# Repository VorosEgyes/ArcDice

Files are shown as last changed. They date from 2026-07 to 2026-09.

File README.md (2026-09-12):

# ArcDice



ArcDice is a compact ATtiny13-based digital dice project with a 7-LED face, low-power sleep behavior, and a matching KiCad hardware design.

Keywords: digital dice, ATtiny13 dice, LED dice, DIY electronic dice.

## What It Does

- Rolls a random value from 1 to 6 with a short LED animation.
- Drives a 7-point dice face from only 4 MCU output lines.
- Uses button wake-up and sleep mode to reduce power draw.

## Firmware

- Source: `src/main.cpp`
- PlatformIO environment: `attiny13a`
- Upload protocol: `usbasp`

### Pin Mapping

- PB0 -> center LED segment
- PB1 -> diagonal A (top-left + bottom-right)
- PB2 -> diagonal B (top-right + bottom-left)
- PB3 -> middle row (left-middle + right-middle)
- PB4 -> roll button (to GND, internal pull-up)

### Dice Face Layout

The 7 visible pips are arranged on a 3x3 grid and lit via 4 logical
groups (center, two diagonals, middle row). The resulting faces are:

| Roll | Pattern | Description |
|---|---|---|
| 1 | center | single center pip |
| 2 | diagonal A | two corner pips (TL+BR) |
| 3 | center + diagonal A | vertical middle column (TL + center + BR) |
| 4 | diagonal A + diagonal B | four corners (full X) |
| 5 | center + both diagonals | full X plus center |
| 6 | both diagonals + middle row | four corners + middle two |

Note: face 3 uses diagonal A (TL+BR) plus center, giving a symmetric
vertical middle column -- the standard 7-pip rendering of 3.

## Hardware

- KiCad project files:
	- `hardware/ArcDice.kicad_pro`
	- `hardware/ArcDice.kicad_sch`
	- `hardware/ArcDice.kicad_pcb`
- Power target: 1S Li-ion/LiPo with TP4056 protected module
- Recommended LED resistors: 220 ohm (one per LED)

## Images

### Assembled Board

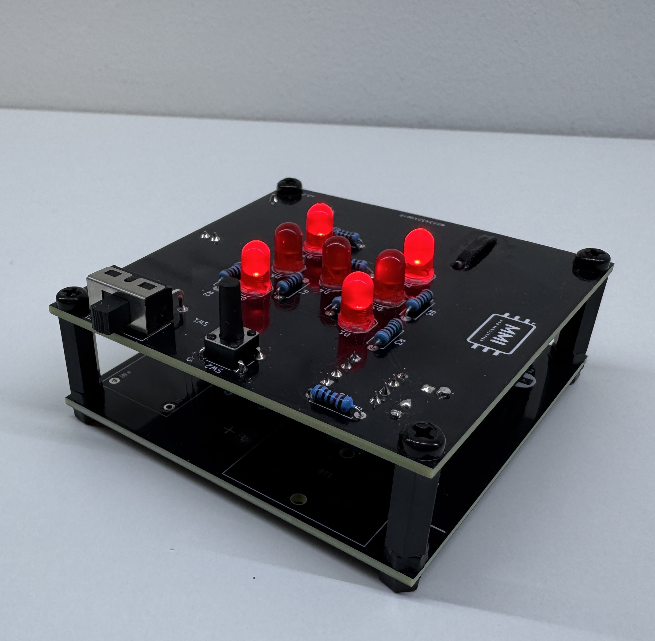
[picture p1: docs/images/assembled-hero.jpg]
ArcDice assembled, all segments lit


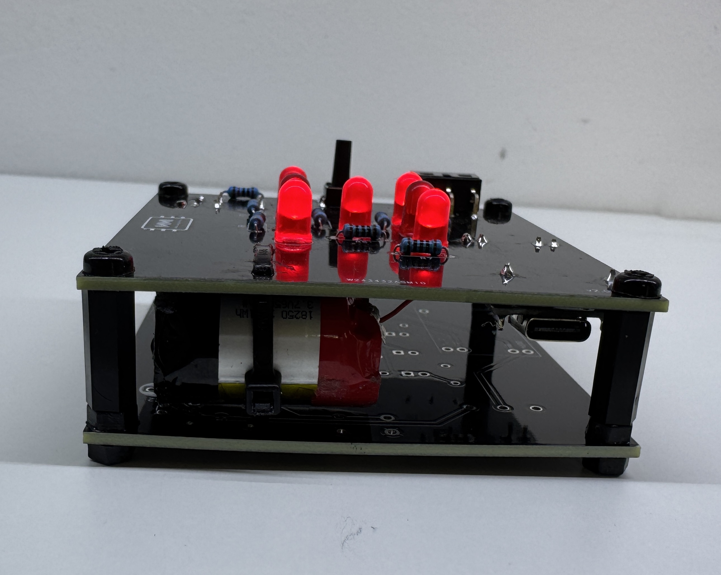
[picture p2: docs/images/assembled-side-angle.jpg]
ArcDice assembled, side angle showing battery


### Bare PCB

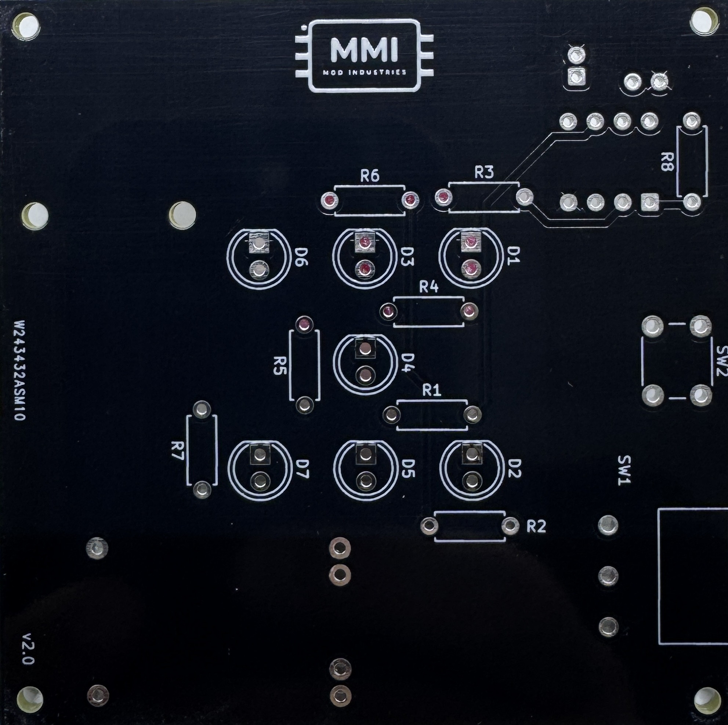
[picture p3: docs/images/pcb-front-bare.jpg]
ArcDice bare PCB, front


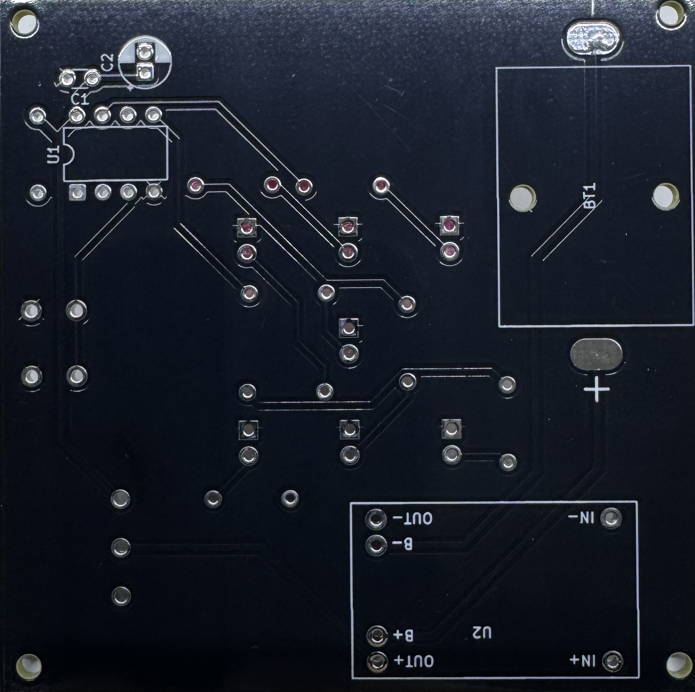
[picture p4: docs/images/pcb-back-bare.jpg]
ArcDice bare PCB, back


### 3D Top

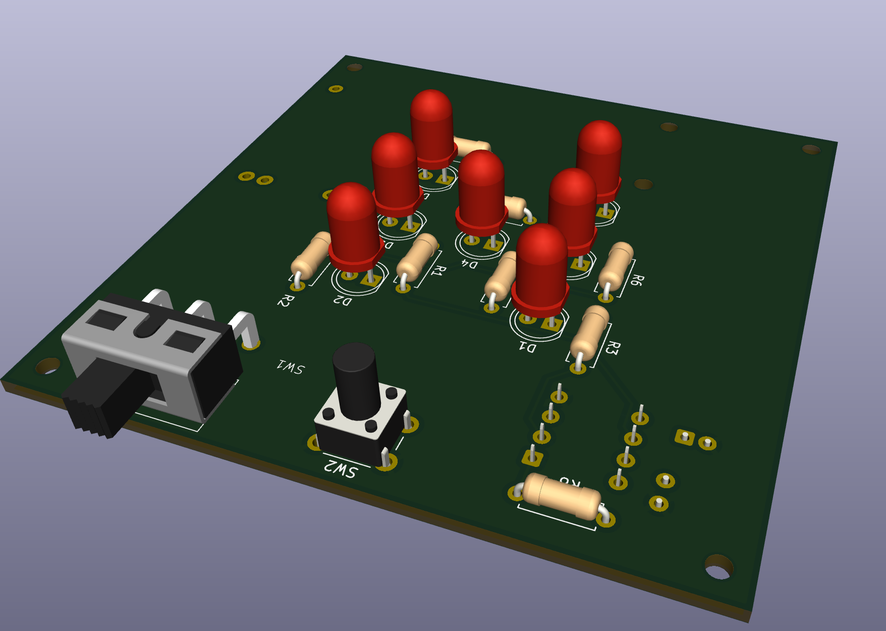
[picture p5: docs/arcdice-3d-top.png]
ArcDice 3D top


### 3D Bottom

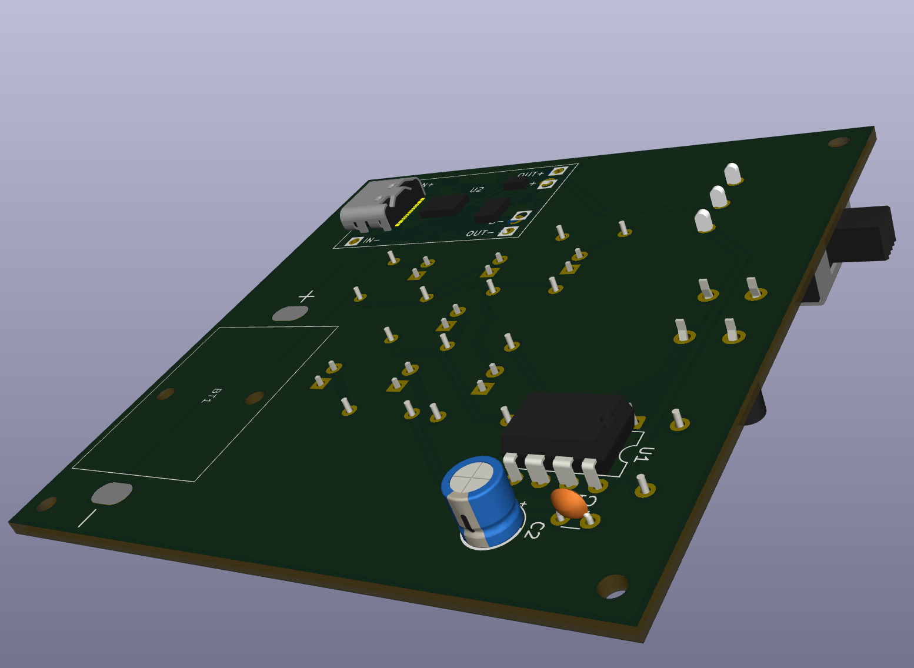
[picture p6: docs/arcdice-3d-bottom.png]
ArcDice 3D bottom


### Schematic v1

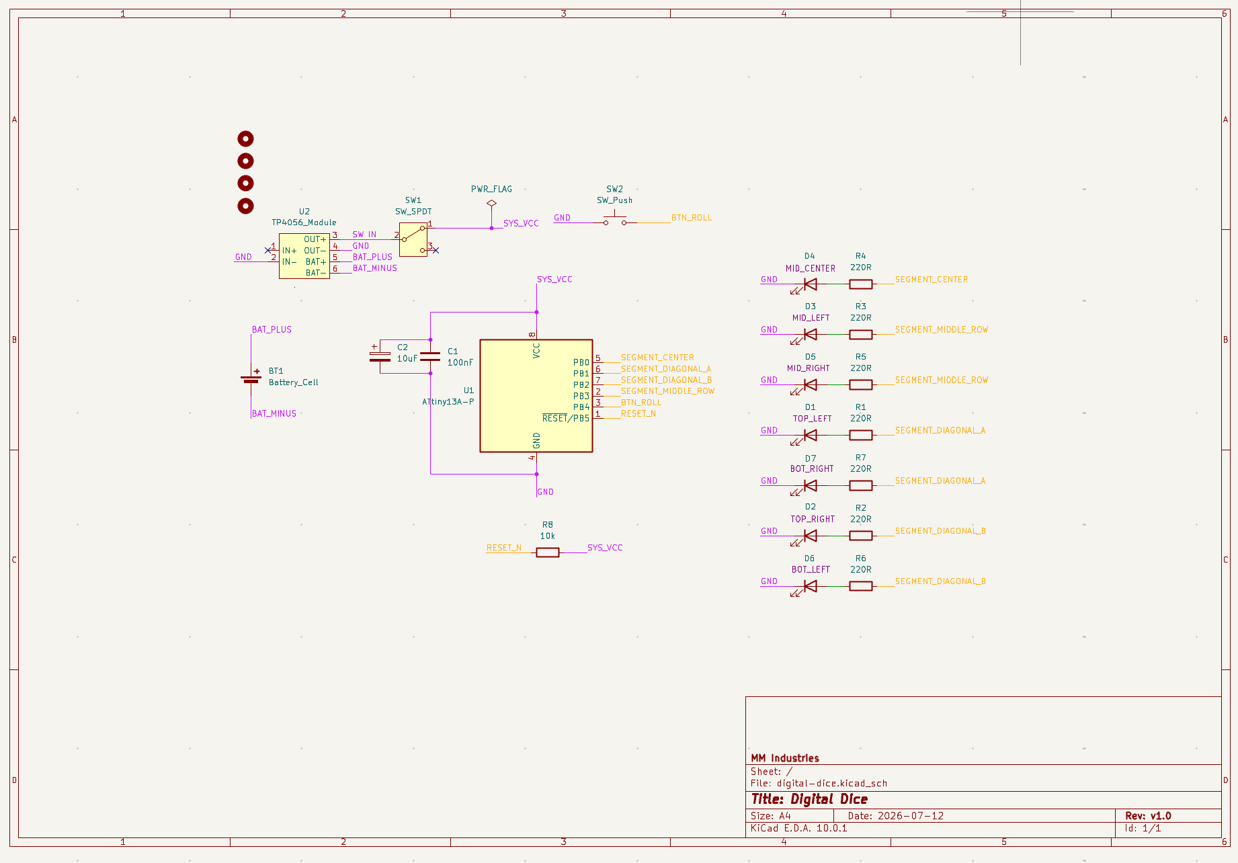
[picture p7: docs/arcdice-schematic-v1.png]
ArcDice schematic v1


## Build And Upload

1. Install PlatformIO.
2. Connect an ATtiny13 programmer (USBasp).
3. Build and upload:

```bash
pio run -e attiny13a -t upload
```

## Additional Documentation

- [CHANGELOG.md](CHANGELOG.md) — release history and notable changes.
- [docs/BOM.md](docs/BOM.md) — bill of materials with footprints and suggested supplier parts.

## License

MIT. See `LICENSE`.

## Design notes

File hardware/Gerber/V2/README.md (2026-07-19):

# Gerber V2 — ArcDice PCB revision 2

This folder contains the PCBWay-ready Gerber archive for ArcDice revision 2.

## Files

| File | Purpose |
|---|---|
| `Archive.zip` | Complete submission package (all files below + job metadata). Send this to PCBWay. |
| `ArcDice-F_Cu.gbr` | Front copper (top layer, signal + 5V + GND pours) |
| `ArcDice-B_Cu.gbr` | Back copper (bottom layer, GND pour) |
| `ArcDice-F_Mask.gbr` | Front soldermask |
| `ArcDice-B_Mask.gbr` | Back soldermask |
| `ArcDice-F_Paste.gbr` | Front solder paste (SMD footprints; this board is through-hole so this layer is mostly empty) |
| `ArcDice-B_Paste.gbr` | Back solder paste |
| `ArcDice-F_Silkscreen.gbr` | Front silkscreen (reference designators, logo, "ArcDice V2") |
| `ArcDice-B_Silkscreen.gbr` | Back silkscreen |
| `ArcDice-Edge_Cuts.gbr` | Board outline |
| `ArcDice-PTH-drl.gbr` | Plated through-hole drill file |
| `ArcDice-NPTH-drl.gbr` | Non-plated through-hole drill file (M2 mounting holes) |
| `ArcDice-job.gbrjob` | KiCad job file describing the export — used by PCBWay to verify the package |

## Specifications

| | |
|---|---|
| **Board dimensions** | (See `ArcDice-Edge_Cuts.gbr` — open in KiCad or any Gerber viewer) |
| **Layers** | 2 (front + back) |
| **Material** | FR4 |
| **Thickness** | 1.6 mm (default; change in PCBWay order form if needed) |
| **Copper weight** | 1 oz/ft² (default) |
| **Surface finish** | HASL lead-free recommended for through-hole; ENIG also fine |
| **Soldermask colour** | Any (green is cheapest; black shows silkscreen best) |
| **Silkscreen colour** | White |
| **Min hole size** | 0.8 mm (drill diameter — through-hole pads) |
| **Min trace / space** | 0.2 mm / 0.2 mm (KiCad default; PCBWay standard) |

## Changes from V1 (if applicable)

*V1 is not in the repository — only V2 shipped publicly.*

If you ordered from a previous (pre-V2) prototype, the main changes were:

- (none — V2 is the first publicly archived revision)

## How to order

1. Go to https://www.pcbway.com/ (or any PCB house: JLCPCB, ALLPCB, etc.).
2. Click **Quick Order** → **Gerber Upload**.
3. Upload `Archive.zip`.
4. PCBWay will parse `ArcDice-job.gbrjob` and pre-fill layer count,
   material, and dimensions. Confirm:
   - **Layers**: 2
   - **Material**: FR4
   - **Thickness**: 1.6 mm
   - **Quantity**: whatever you need (5 / 10 / 30 / 50).
5. Add to cart. Choose shipping. Done.

For assembly, see [`../docs/BOM.md`](../docs/BOM.md) for the through-hole
parts. This board has no SMD components, so hand-soldering or wave
soldering both work; reflow is not required.

## Reproducing the Gerber export

If you change the schematic or PCB and want to regenerate this folder:

1. Open `../ArcDice.kicad_pro` in KiCad 8 or later.
2. **Plot** → choose **Gerber** as the format.
3. Select **all layers** you want (F.Cu, B.Cu, F.Mask, B.Mask,
   F.Paste, B.Paste, F.SilkS, B.SilkS, Edge.Cuts).
4. Check **Use Protel filename extensions** is enabled (so the
   `.gbr` filenames match).
5. Click **Plot**.
6. **Generate Drill Files** → PTH and NPTH in separate files.
   Use **Gerber X2** format.
7. Archive the generated `.gbr` + `.drl` + `*-job.gbrjob` into
   `Archive.zip`.
8. Move the previous folder to `Gerber/V3/`, update this README with
   the change log, and tag the commit as `hw-v3`.

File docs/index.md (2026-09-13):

---
layout: default
title: ATtiny13 Digital Dice
---

<div class="hero">
  <div class="hero-text">
    <h1>ArcDice</h1>
    <p class="tagline">An open-source digital dice built from an ATtiny13A — 1 KB of flash, 7 LEDs, one button, infinite rolls.</p>
    <div class="cta-row">
      <a class="cta-button" href="{{ '/#download' | relative_url }}">Download v1.1.0</a>
      <a class="cta-button secondary" href="{{ site.github_url }}">View on GitHub ↗</a>
      <a class="cta-button secondary" href="{{ '/#demo' | relative_url }}">Watch demo</a>
    </div>
  </div>
  <div class="hero-image">
    ArcDice assembled prototype with all 7 LEDs lit showing a 6
  </div>
</div>

## What is it?

ArcDice is a complete DIY electronics project: a pocket-sized digital dice you build yourself. Press the button, watch the 7-LED display animate, and a random number from 1 to 6 appears.

It's built around an **ATtiny13A** — one of the smallest AVR microcontrollers Atmel makes, with just **1 KB of flash** and **64 bytes of RAM**. Driving 7 LEDs from only 4 I/O pins uses a clever charlieplexing scheme; the firmware fits in 598 bytes (58.4% of available flash).

The hardware is open (KiCad schematics + PCB layout, MIT licensed), the firmware is open (C++, 39 source files, host-native unit tests), and the BOM has 10 component lines / 26 parts — most of which you probably already have in your parts bin.

## Hardware

- **MCU**: ATtiny13A in DIP-8 (8-bit AVR, 1 KB flash, 64 B RAM, internal 9.6 MHz oscillator)
- **Display**: 7 red LEDs arranged in the classic dice-6 pattern, charlieplexed on PB0–PB3
- **Input**: Single tactile button (wake from sleep on press)
- **Power**: TP4056 Li-ion/LiPo charger module (USB-C or micro-USB variant) with built-in DW01 + FS8205 protection IC
- **Cell**: 1S Li-ion/LiPo (protected, user-supplied, ~600 mAh gives weeks of standby)

### PCB

<div class="gallery-grid">
  <div class="gallery-item">
    PCB front side, unpopulated
    <p class="gallery-caption">PCB front side (bare)</p>
  </div>
  <div class="gallery-item">
    PCB back side, unpopulated
    <p class="gallery-caption">PCB back side (bare)</p>
  </div>
</div>

### Specifications

<table class="spec-table">
  <tr><th>Hardware revision</th><td>v2.1 (KiCad)</td></tr>
  <tr><th>PCB size</th><td>~30 × 30 mm</td></tr>
  <tr><th>Layers</th><td>2 (top + bottom)</td></tr>
  <tr><th>BOM</th><td>10 component lines, 26 parts total</td></tr>
  <tr><th>Power consumption (idle)</th><td>< 10 µA (sleep mode)</td></tr>
  <tr><th>Power consumption (roll)</th><td>~15 mA peak (all 7 LEDs)</td></tr>
  <tr><th>Build time</th><td>~30 minutes (THT parts only)</td></tr>
  <tr><th>License</th><td>MIT</td></tr>
</table>

## Demo

<div class="demo-gif">
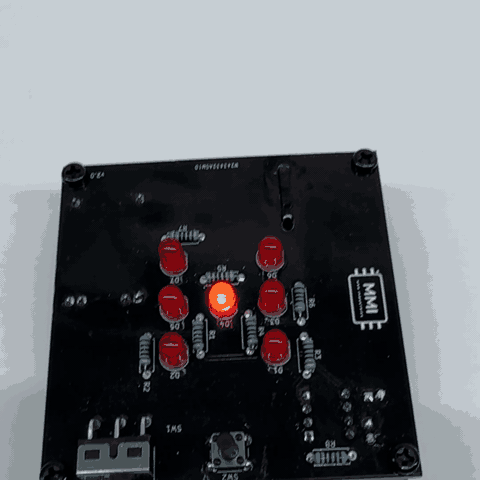
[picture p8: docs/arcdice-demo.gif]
ArcDice demo: button press animates LEDs to a 3
  
  <p><em>Press the button — the 7 LEDs animate for ~1.5 seconds, then settle on a random number from 1 to 6.</em></p>
</div>

The dice face logic is unit-tested against the canonical patterns in `include/dice.h`, with a host-native test runner that runs on any laptop in under a second (`pio test -e native`).

## Gallery

<div class="gallery-grid">
  <div class="gallery-item">
    Assembled ArcDice showing a 6
    <p class="gallery-caption">All 7 LEDs lit — a 6</p>
  </div>
  <div class="gallery-item">
    Side angle showing PCB thickness
    <p class="gallery-caption">Side view — battery + TP4056 visible</p>
  </div>
  <div class="gallery-item">
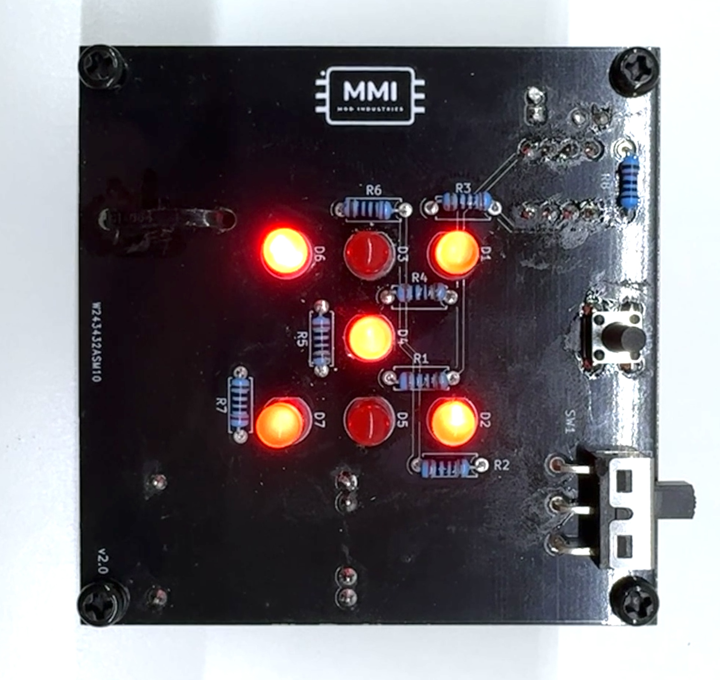
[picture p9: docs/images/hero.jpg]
Hero shot, top-down
    
    <p class="gallery-caption">Top-down view</p>
  </div>
</div>

## Build it yourself

The project ships with everything you need:

- **Pre-compiled firmware** (`ArcDice_v1.1.0_firmware.hex`) — flash with a $5 USBasp and `avrdude` in 30 seconds
- **Gerber package** (`ArcDice_v2.1_gerber.zip`) — upload the inner `Archive.zip` to PCBWay or JLCPCB; ~$5 for 5 boards
- **BOM CSV** (`ArcDice_v2.1_bom.csv`) — 10 lines with KiCad footprints and suggested supplier parts (Digi-Key / LCSC / Mouser)
- **Assembly guide** — step-by-step build instructions with a troubleshooting table

Total cost of parts: roughly **$8–12** if you're sourcing everything new, less if you have a parts bin.

```bash
# Flash the firmware
avrdude -c usbasp -p attiny13 -U flash:w:ArcDice_v1.1.0_firmware.hex:i
```

The full build takes about 30 minutes if you've soldered through-hole before.

## Download

Latest release: **[v1.1.0 — Hardware v2.1]({{ site.github_url }}/releases/tag/v1.1.0)** (2026-09-11)

| Asset | Size | Description |
|---|---:|---|
| [ArcDice_v1.1.0_firmware.hex]({{ site.github_url }}/releases/download/v1.1.0/ArcDice_v1.1.0_firmware.hex) | 1.7 KB | Pre-compiled ATtiny13A firmware |
| [ArcDice_v2.1_gerber.zip]({{ site.github_url }}/releases/download/v1.1.0/ArcDice_v2.1_gerber.zip) | 208 KB | PCBWay-ready Gerber package |
| [ArcDice_v2.1_bom.csv]({{ site.github_url }}/releases/download/v1.1.0/ArcDice_v2.1_bom.csv) | 2.7 KB | Bill of Materials (10 lines, 26 parts) |
| [ArcDice_v2.1_assembly_guide.md]({{ site.github_url }}/releases/download/v1.1.0/ArcDice_v2.1_assembly_guide.md) | 4.8 KB | 6-step build instructions |

**SHA256** (firmware):
```
3bb64ebeb0fcdb910fa978c3b29c1daba74df96bf88c5c467d6e60e317c714ee
```

Always verify before flashing.

## License

MIT — see [LICENSE]({{ site.github_url }}/blob/main/LICENSE). Schematics, PCB layout, and firmware are all released under the same terms. Feel free to fork, modify, and build your own version.

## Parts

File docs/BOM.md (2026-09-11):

# Bill of Materials (BOM)

This document lists every component needed to build one ArcDice unit.
It is derived from the KiCad project (`hardware/ArcDice.kicad_pro`,
`.kicad_sch`, `.kicad_pcb`) and the firmware pin mapping in
`src/main.cpp`. Footprints are taken straight from the KiCad library
references.

> **Sourcing note** — KiCad footprints identify the *physical package*
> (e.g. `LED_D5.0mm`, `R_Axial_DIN0207`). For exact distributor part numbers
> (Digi-Key, Mouser, LCSC), see the *Suggested supplier parts* column. Any
> equivalent part that matches footprint and electrical specs will work.

## Components

| Ref | Qty | Part (KiCad) | Description | Footprint / package | Suggested supplier part |
|----:|----:|---|---|---|---|
| U1 | 1 | `ATtiny13A-P` | 8-bit AVR MCU, 1 KB flash, 64 B EEPROM, 64 B SRAM, internal 9.6 MHz oscillator | DIP-8 (through-hole) | Microchip ATtiny13A-PU (Digi-Key ATATTINY13A-PU-ND) |
| D1–D7 | 7 | `LED` (generic) | 5 mm through-hole LED — pick your colour (red, yellow, green, blue, white all fit). Forward voltage ~2.0 V (red) to ~3.2 V (blue/white) at 20 mA | `LED_THT:LED_D5.0mm` | Kingbright L-7113ID (red, THT, 5 mm) or any 5 mm LED of your choice |
| R1–R7 | 7 | Resistor 220 Ω, ¼ W | LED current-limiting. With 3.0 V Li-ion and a red LED (~2 V Vf), 220 Ω gives ~5 mA per LED — plenty for a battery-powered dice | `Resistor_THT:R_Axial_DIN0207_L6.3mm_D2.5mm_P7.62mm_Horizontal` | Yageo MFR-25FBF52-220R (Digi-Key 220XBK-ND) |
| SW1 | 1 | `SW_Push` — roll button | 6 mm × 9.5 mm through-hole tactile push button, SPST-NO. Connected to PB4 to GND, internal pull-up enabled in firmware | `Button_Switch_THT:SW_PUSH_6mm_H9.5mm` | C&K PTS810SJM250SMTRLFS or any equivalent 6 mm THT tactile |
| SW2 | 1 | `Switch_Slide_SS12D06_Generic` | SPDT slide switch — most likely the power on/off switch between battery and TP4056 / load | `Button_Switch_THT:Switch_Slide_SS12D06_Generic` | SS12D06G3 or any equivalent SPDT slide switch, THT |
| SW3 | 1 | `SW_SPDT` | Second SPDT switch — check schematic for exact use (likely mode-select or reset disable) | (KiCad symbol `Switch:SW_SPDT`, footprint TBD) | Any SPDT THT slide/toggle switch |
| BT1 | 1 | `Battery_Cell` | Single 3.7 V Li-ion / LiPo cell (1S), nominal capacity 100–500 mAh typical for a dice. Use a protected cell (with BMS) and add a 1N4148 flyback diode if driving the LEDs without other regulation | Through-hole battery holder footprint (KiCad `Device:Battery_Cell`) | 1S Li-ion/LiPo |
| U2 | 1 | `TP4056_Module` | TP4056 Li-ion/LiPo linear charging module, micro-USB or USB-C input depending on the module variant. Charges the cell from any 5 V source; module typically includes a DW01 + FS8205 protection IC. Note: the **module** is mounted, not the bare TP4056 IC | Through-hole 4-pin module (OUT+/OUT−/IN+/IN−) | TP4056 micro-USB module (LCSC C103626) or USB-C variant (LCSC C2932096) |
| C1, C2 | 2 | Decoupling capacitors | Polarized + unpolarized decoupling. Typical: 100 nF ceramic (unpolarized) on ATtiny AVCC, and 10 µF electrolytic (polarized) across battery / TP4056 output for smooth LED current | THT, 5 mm pitch (KiCad `Device:C` and `Device:CP`) | Murata RDER71H104K (100 nF) + Nichicon UPW1A100MDD (10 µF) |
| H1–H4 | 4 | M2 mounting holes, 2.2 mm drill | Mechanical mounting only — use with M2 × 4 (or longer) pan-head screws and (optional) 4 mm hex spacers | `MountingHole:MountingHole_2.2mm_M2` | M2 × 4 pan-head screw + M2 hex spacer, 4 each |

## Component count summary

- **Active:** 1 MCU + 1 charger module = **2**
- **Passive:** 7 resistors + 2 capacitors = **9**
- **LEDs:** 7
- **Switches:** 3 (1 push button + 2 SPDT slide switches)
- **Battery:** 1 cell (1S Li-ion/LiPo, user-supplied, not part of a bare kit)
- **Mechanical:** 4 M2 mounting holes

## What is NOT on this BOM

- **USBasp programmer** — required to flash the ATtiny13A initially, but not part of the assembled board.

- **Battery** — listed above for reference but typically user-supplied (a protected 1S cell with leads).
- **Enclosure / 3D-printed case** — not in the current hardware design.

## Notes for sourcing

1. **LED colour** — pick whatever you prefer; the firmware doesn't depend on it. If you mix colours, double-check the forward voltage: a 220 Ω resistor is fine for red/yellow/green (~2 V Vf). For blue/white (~3 V Vf) you'll want closer to 100 Ω to keep the LED brightness matched at ~5–10 mA.
2. **Resistor power rating** — 220 Ω × 5 mA = ~5.5 mW per resistor, so ¼ W is enormous overkill; even 1/8 W works.
3. **TP4056 module vs. bare IC** — the BOM uses the *module*, not the bare TP4056 IC, because the module integrates the DW01 + FS8205 protection and the micro-USB connector. If you want to redesign around the bare IC (smaller PCB, no on-board USB), that is a v2 hardware decision, not a BOM change.
4. **Battery polarity** — make sure your 1S cell has a protection circuit (BMS). The TP4056 module by itself does not include over-discharge protection.

## Sourcing shortcuts

| Supplier | Region | Best for |
|---|---|---|
| LCSC | China / EU warehouse | TP4056 module, basic passives, LEDs |
| Digi-Key | Worldwide | ATtiny13A-PU (genuine Microchip), quality passives |
| Mouser | Worldwide | Same as Digi-Key, often better for European orders |
| TME | EU (Hungary-friendly) | Through-hole resistors, capacitors, LEDs, switches |
| Reichelt | DE / EU | German warehouse, good for DIN0207 resistors |
| AliExpress | China | Cheapest TP4056 modules and LEDs, expect 2–4 week shipping |

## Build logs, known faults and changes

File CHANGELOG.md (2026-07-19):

# Changelog

All notable changes to ArcDice will be documented in this file.

The format is based on [Keep a Changelog](https://keepachangelog.com/en/1.1.0/),
and this project adheres to [Semantic Versioning](https://semver.org/spec/v2.0.0.html).

## [Unreleased]

### Planned
- Detailed assembly guide with HV programming instructions for `RSTDISBL`
  (deferred — see the discussion in the release-readiness audit, the
  ATtiny13A HV fuse programming is documented separately).
- Initial public **v1.0.0** release (this section is collapsed into the
  [1.0.0] entry below once the release tag is pushed).

## [1.0.0] - 2026-07-19

**First public release.** Suitable for small-batch manufacturing of the
ArcDice 7-LED digital dice kit. KiCad `V2` hardware, MIT-licensed
firmware, full bill of materials, host-native unit tests, and CI build.

### Highlights
- **ATtiny13A firmware** with button-wake sleep, BOD disable during
  sleep, edge-accumulated PRNG entropy, and a startup "all-segments-on"
  flash to surface dead-segment faults immediately.
- **KiCad `V2` hardware design** with 5 mm through-hole LEDs, axial
  DIN0207 resistors, USBasp-friendly ISP header, TP4056 Li-ion charger
  module, and 1S battery footprint. PCBWay-ready Gerber archive is
  bundled under `hardware/Gerber/V2/`.
- **Documented `RSTDISBL` trade-off** — PB4 doubles as the roll
  button and the ATtiny13A RESET pin, so a high-voltage programmer is
  required once the button-only variant is programmed.
- **Full [BOM](docs/BOM.md)** with footprints and suggested supplier
  parts (LCSC, Digi-Key, Mouser, TME, Reichelt, AliExpress).
- **GitHub Actions CI** (`Build & Test` workflow): host-native Unity
  tests gate every AVR build, the firmware size check fails if the
  `.text` section exceeds the 1024-byte ATtiny13A flash budget, and
  the resulting `firmware.hex` + `firmware.elf` are uploaded as a
  14-day artifact.
- **Refactored face-mask logic** in `include/dice.h` as `constexpr`
  values, so the host test runner can validate face-mapping without an
  AVR toolchain.

### Changed since 0.9.0
- No code changes — the `0.9.0` pre-release is functionally identical to
  `1.0.0`. The version bump reflects the addition of the documentation,
  tests, and CI that 0.9.0 was missing.

### Notes for downstream users
- **Programming**: connect a USBasp, build with `pio run -e attiny13a`,
  upload with `pio run -e attiny13a -t upload`. The shipped firmware
  assumes the `RSTDISBL` fuse is already programmed (see README for
  the trade-off and HV programming alternatives).
- **Battery**: use a protected 1S Li-ion/LiPo cell. The TP4056 module
  on board is a charger, not a BMS.
- **LEDs**: 5 mm through-hole, any colour. Forward voltage considerations
  for the 220 Ω current-limiting resistors are in `docs/BOM.md`.

## [0.9.0] - 2026-07-18

First pre-release candidate suitable for small-batch manufacturing (KiCad `V2`).

### Added
- **7-segment dice face documentation**: full table of 1–6 pip layouts, with
  explicit description of which segments form each face.
- **RSTDISBL trade-off warning** in the README and as a top-of-file comment in
  `src/main.cpp`. PB4 (button input) is the ATtiny13A RESET pin; using it
  requires the `RSTDISBL` fuse to be programmed, which **disables ISP
  reprogramming** and requires a high-voltage programmer for any further
  firmware changes.
- **`hardware/Gerber/V2/` archive** (PCBWay-ready ZIP: `Archive.zip`,
  106 KB) including F/B copper, mask, paste, silkscreen, edge cuts, NPTH
  and PTH drill files, plus the `job.gbrjob` summary.

### Changed
- **BOD disable ordering** in `goToSleep()`: moved `sleep_bod_disable()` so
  it runs within the 3-cycle window after `sleep_enable()` as required by
  the ATtiny13A datasheet. Saves ~25 µA in sleep mode.
- **Edge entropy accumulation** in the PCINT0 ISR: entropy is now XOR-accumulated
  across multiple edges instead of overwritten on each interrupt. Combined
  with `TCNT0` and `PINB` samples, gives stronger per-press randomness.
- **Startup flash** in `runStartupTest()`: now ends with a 200 ms
  "all-segments-on" flash before clearing the display, so a dead segment or
  swapped wiring is immediately obvious (the 1..6 cycle hides such faults).
- **Explicit sleep sequence** in `goToSleep()`: replaced `sleep_mode()` with
  `sei() → sleep_cpu() → sleep_disable()` to avoid racing with a pending
  PCINT (which would cause immediate wake-up).
- **Repo hygiene**: `.DS_Store`, `hardware/.DS_Store`, and
  `.vscode/settings.json` removed from version control; `.gitignore` extended
  to keep them out (KiCad local artifacts, VS Code cache, macOS Finder
  metadata already covered).

### Hardware (KiCad `V2`)
- 7 through-hole LEDs, 5 mm diameter.
- 7 axial DIN0207 resistors (220 Ω, one per LED).
- 1 through-hole tactile push button (6 mm, 9.5 mm height) for the roll input.
- 1 slide switch (SS12D06 generic) — likely power on/off.
- 1 SPDT switch.
- 1 TP4056 Li-ion/LiPo charging module on board.
- 1 ATtiny13A-P MCU (DIP-8, through-hole, re-programmable via USBasp unless
  `RSTDISBL` is set).
- 1 single-cell battery footprint.
- 4 M2 mounting holes (2.2 mm drill).

## [0.5.0] - 2026-07-15

Hardware visualization pass.

### Added
- 3D top and 3D bottom renders of the PCB under `docs/`.
- Schematic v1 render (`docs/arcdice-schematic-v1.png`).

### Changed
- KiCad PCB layout refined (commit `c4ac4e9`).

## [0.4.0] - 2026-07-14

Hardware and documentation overhaul: project naming, schematic and PCB
files moved into a self-contained `hardware/` folder.

### Added
- Hardware folder structure: `hardware/ArcDice.kicad_pro`, `.kicad_sch`, `.kicad_pcb`.
- Project renamed: `digital-dice` → `ArcDice` (KiCad project files).
- Rendered images: 3D top, 3D bottom, schematic v1 under `docs/`.

### Removed
- Old `docs/kicad-schematic-checklist.md` and `docs/schematic-v1.md`
  (the checklist is now embedded in the README and KiCad files themselves).
- Empty `include/README`, `lib/README`, `test/README` placeholder files
  (the empty folders themselves are still present and tracked).

## [0.3.0] - 2026-07-12

Initial firmware and hardware design in the repo.

### Added
- `LICENSE` (MIT).
- `src/main.cpp` with the full dice-rolling logic: PRNG, button interrupt,
  sleep mode, dice face mask table, startup test, pin mapping.
- KiCad schematic and PCB project (originally named `digital-dice`).
- `platformio.ini` configured for `attiny13a` env, USBasp upload protocol.
- Extended `.gitignore` for KiCad local artifacts and PlatformIO `.pio/`.
- Internal documentation: `docs/kicad-schematic-checklist.md`,
  `docs/schematic-v1.md`.

## [0.2.0] - 2024-11-03

Documentation refresh.

### Changed
- README updated with project description, build instructions, and
  ATtiny13A-specific notes.

## [0.1.0] - 2023-11-24

Initial commit.

### Added
- Empty PlatformIO project skeleton (`platformio.ini`, `src/main.cpp`,
  `include/`, `lib/`, `test/`).
- `.gitignore` covering build outputs.
- `.vscode/extensions.json` recommending PlatformIO IDE.
- First README.

[Unreleased]: https://github.com/VorosEgyes/ArcDice/compare/v1.0.0...HEAD
[1.0.0]: https://github.com/VorosEgyes/ArcDice/compare/380ab67...v1.0.0
[0.9.0]: https://github.com/VorosEgyes/ArcDice/compare/c320930...380ab67
[0.5.0]: https://github.com/VorosEgyes/ArcDice/compare/7bee596...afaace9
[0.4.0]: https://github.com/VorosEgyes/ArcDice/compare/b4b2c73...7bee596
[0.3.0]: https://github.com/VorosEgyes/ArcDice/compare/8829135...b4b2c73
[0.2.0]: https://github.com/VorosEgyes/ArcDice/compare/8829135...d1e2978
[0.1.0]: https://github.com/VorosEgyes/ArcDice/tree/c320930

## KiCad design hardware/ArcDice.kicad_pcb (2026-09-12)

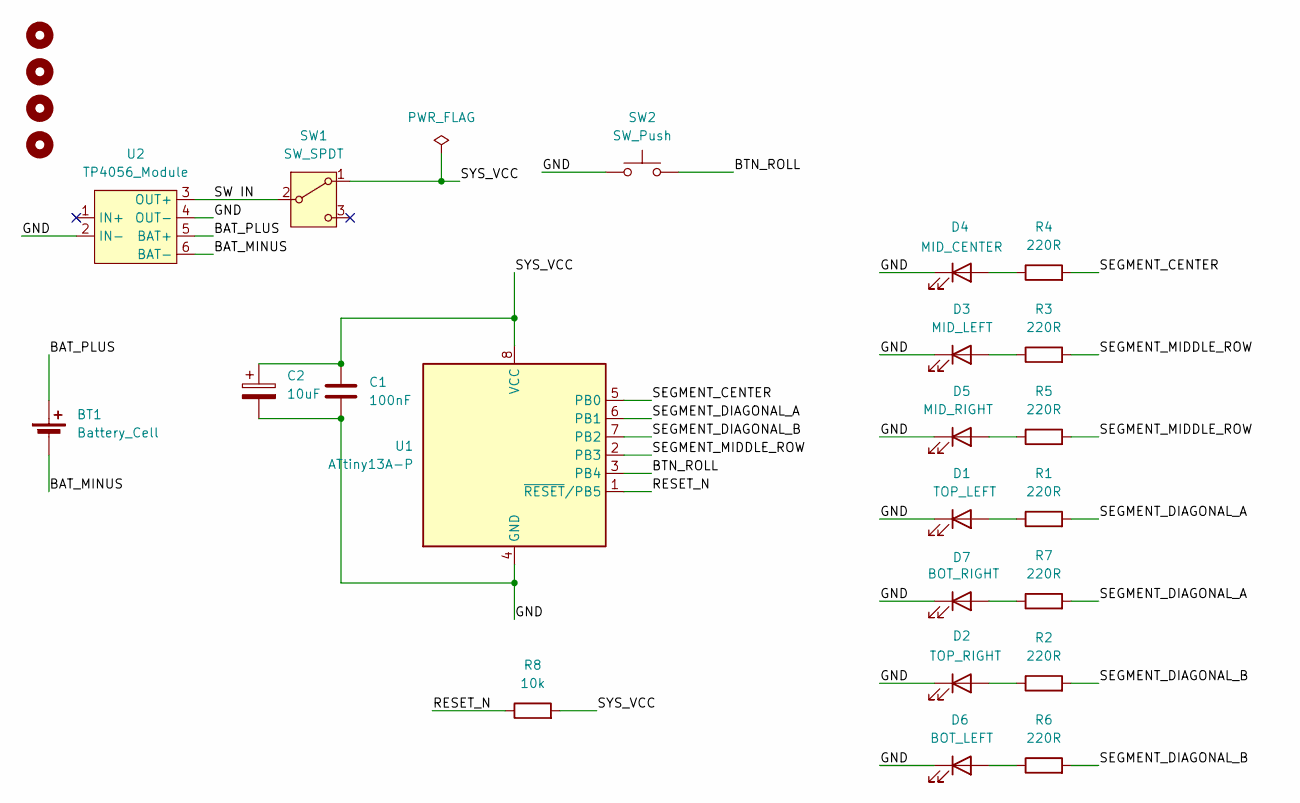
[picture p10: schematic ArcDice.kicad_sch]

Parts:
BT1: Battery_Cell; Battery_18250_Tabbed_1S
C1: 100nF; C_Disc_D3.0mm_W1.6mm_P2.50mm
C2: 10uF; CP_Radial_D5.0mm_P2.00mm
D1, D2, D3, D4, D5, D6, D7: LED; LED_D5.0mm
H1, H2, H3, H4: MountingHole; MountingHole_3.2mm_M3
R1, R2, R3, R4, R5, R6, R7: 220R; R_Axial_DIN0207_L6.3mm_D2.5mm_P7.62mm_Horizontal
R8: 10k; R_Axial_DIN0207_L6.3mm_D2.5mm_P7.62mm_Horizontal
SW1: SW_SPDT; Switch_Slide_SS12D06_Generic
SW2: SW_Push; SW_PUSH_6mm_H9.5mm
U1: ATtiny13A-P; DIP-8_W7.62mm
U2: TP4056_Module; TP4056-Module

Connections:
/BAT_MINUS: BT1.2 (-), U2.6 (BAT-)
/BAT_PLUS: BT1.1 (+), U2.5 (BAT+)
/BTN_ROLL: SW2.2, U1.3 (PB4)
/GND: C1.2, C2.2, D1.1 (K), D2.1 (K), D3.1 (K), D4.1 (K), D5.1 (K), D6.1 (K), D7.1 (K), SW2.1, U1.4 (GND), U2.2 (IN-), U2.4 (OUT-)
/RESET_N: R8.1, U1.1 (~RESET/PB5)
/SEGMENT_CENTER: R4.2, U1.5 (PB0)
/SEGMENT_DIAGONAL_A: R1.2, R7.2, U1.6 (PB1)
/SEGMENT_DIAGONAL_B: R2.2, R6.2, U1.7 (PB2)
/SEGMENT_MIDDLE_ROW: R3.2, R5.2, U1.2 (PB3)
/SW IN: SW1.2 (B), U2.3 (OUT+)
/SYS_VCC: C1.1, C2.1, R8.2, SW1.1 (A), U1.8 (VCC)
unnamed: D1.2 (A), R1.1
unnamed: D2.2 (A), R2.1
unnamed: D3.2 (A), R3.1
unnamed: D4.2 (A), R4.1
unnamed: D5.2 (A), R5.1
unnamed: D6.2 (A), R6.1
unnamed: D7.2 (A), R7.1

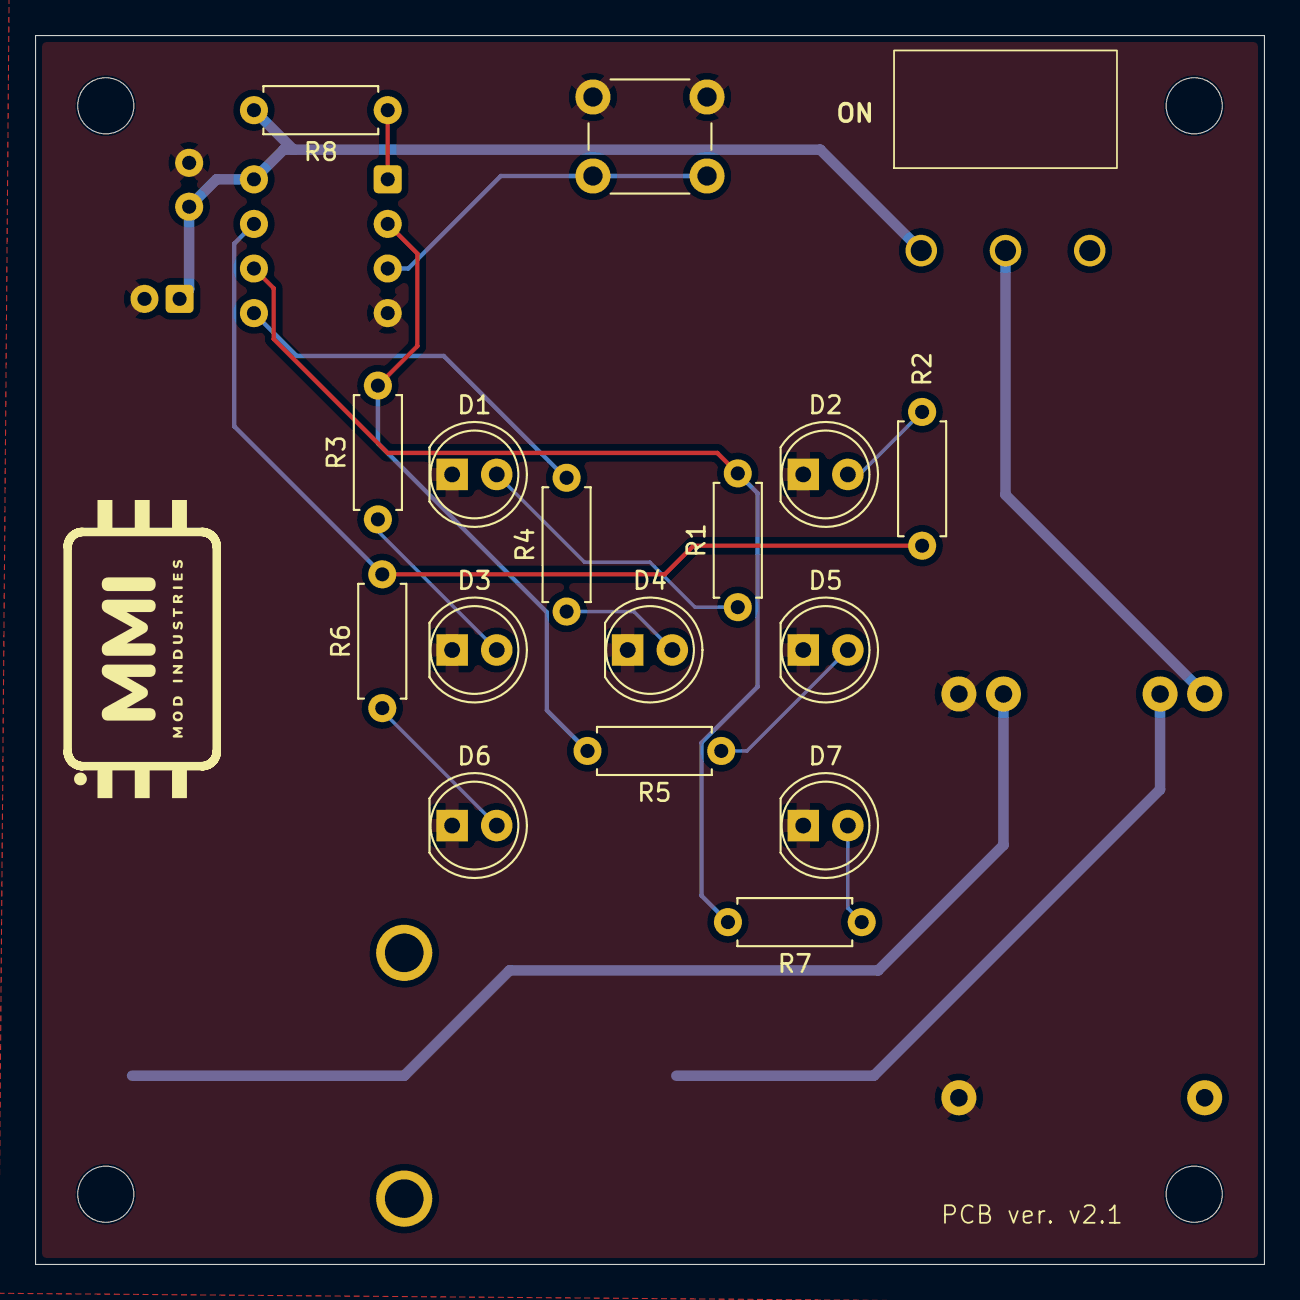
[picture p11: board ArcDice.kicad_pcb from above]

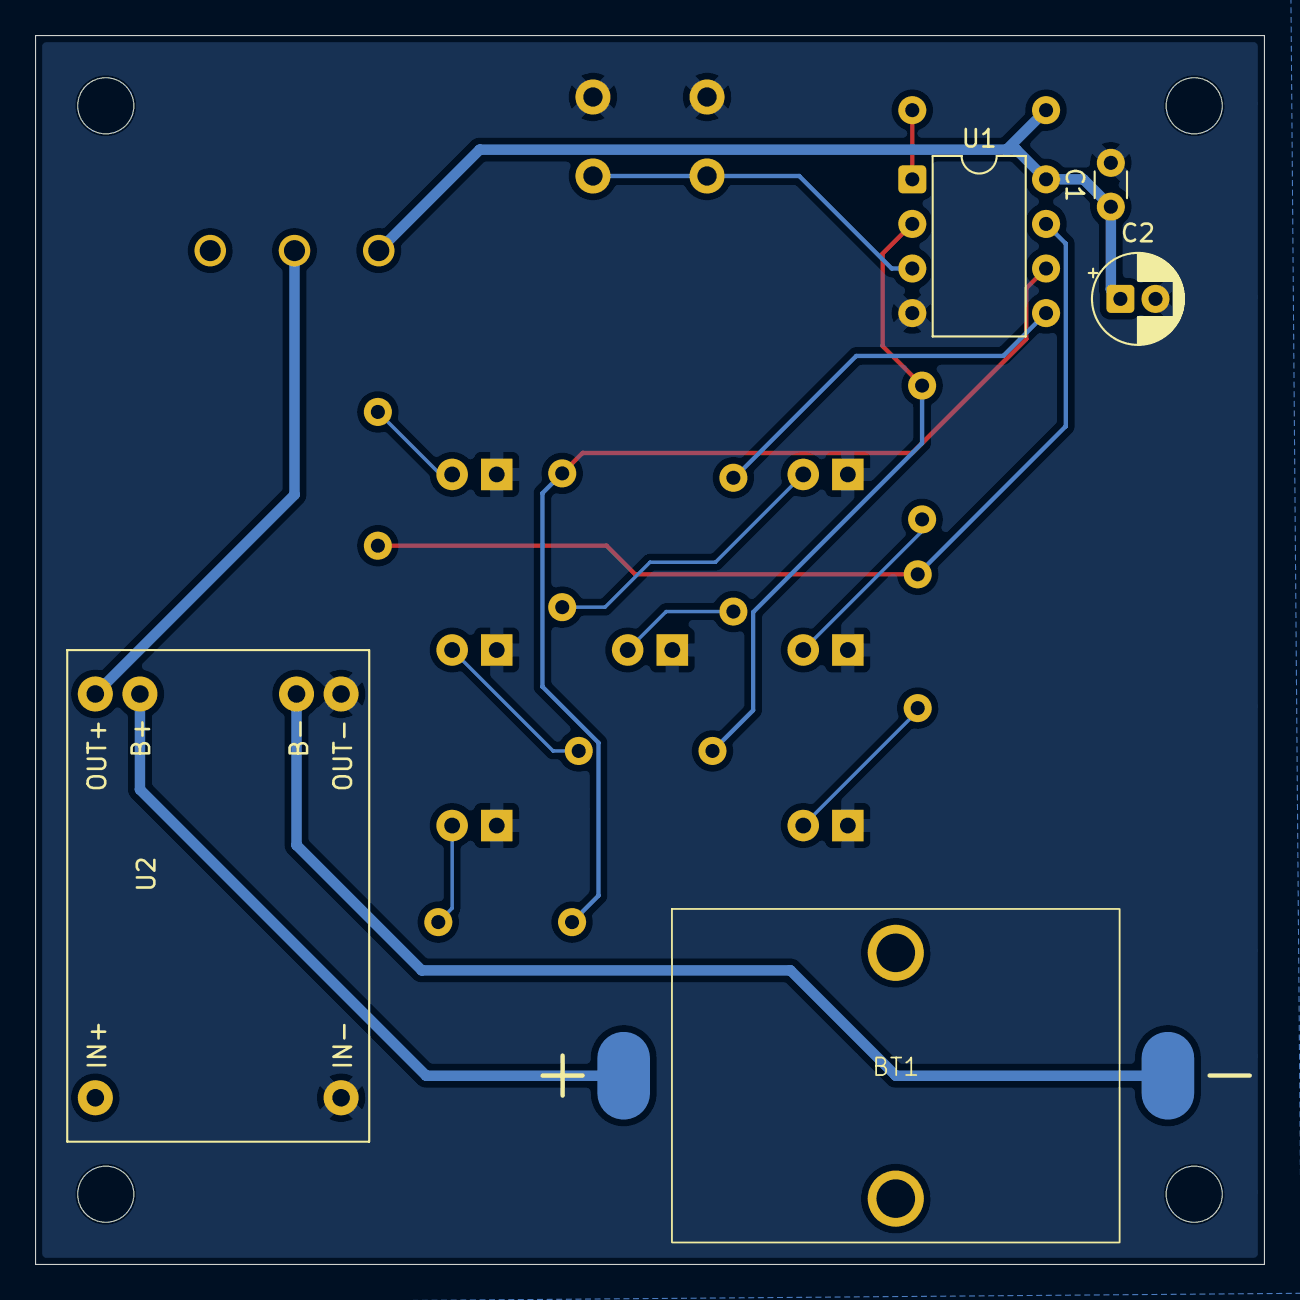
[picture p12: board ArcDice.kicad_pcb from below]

Board: 2 copper layers, 70.0 x 70.0 mm, 26 parts (5 on the bottom side), 18 nets.

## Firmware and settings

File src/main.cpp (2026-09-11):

#include <Arduino.h>
#include <avr/sleep.h>
#include "dice.h"

// LED group layout on the 3x3 dice face:
//
//   TL  TM  TR
//   ML  CC  MR        CC   = center       (SEGMENT_CENTER)
//   BL  BM  BR        ML/MR = middle row  (SEGMENT_MIDDLE_ROW)
//                      TL/BR = diagonal A  (SEGMENT_DIAGONAL_A)
//                      TR/BL = diagonal B  (SEGMENT_DIAGONAL_B)
//
// The constants below come from include/dice.h so the host-native test
// runner can validate face-mask logic without an AVR toolchain.
using arcdice::kDisplayMask;
using arcdice::kButtonMask;
using arcdice::kDiceFaceMasks;
using arcdice::kCenterMask;
using arcdice::kDiagonalAMask;
using arcdice::kDiagonalBMask;
using arcdice::kMiddleRowMask;

volatile bool buttonInterruptPending = false;
volatile uint8_t randomEntropy = 0;
volatile uint8_t edgeCounter = 0;
volatile uint8_t prngState = 0x5A;

void showFace(uint8_t face) {
  PORTB = (PORTB & ~kDisplayMask) | kDiceFaceMasks[face];
}

uint8_t nextRandomByte() {
  uint8_t lsb = prngState & 1;
  prngState >>= 1;
  if (lsb) {
    prngState ^= 0xB8;
  }
  return prngState;
}

void mixEntropy(uint8_t entropy) {
  prngState ^= entropy ^ TCNT0;
  if (!prngState) {
    prngState = 0x5A;
  }
}

uint8_t randomFace() {
  return (nextRandomByte() % 6) + 1;
}

// Waits up to `ms`, 1 ms at a time, so a fresh button press can interrupt
// an in-progress animation immediately instead of waiting for it to finish.
bool waitOrPressed(uint16_t ms) {
  for (uint16_t i = 0; i < ms; ++i) {
    delay(1);
    if (buttonInterruptPending && !(PINB & kButtonMask)) {
      return true;
    }
  }
  return false;
}

// Number of spin steps in a real roll (see performRoll()).
const uint8_t kDemoSpinCount = 8;

void runStartupTest() {
  // Running-light demo: chases through the 4 LED groups starting top-right
  // (diagonal B), 3 full laps around, then goes dark.
  const uint8_t sequence[4] = {
    kDiagonalBMask, kMiddleRowMask, kDiagonalAMask, kCenterMask
  };
  for (uint8_t lap = 0; lap < 3; ++lap) {
    for (uint8_t i = 0; i < 4; ++i) {
      PORTB = (PORTB & ~kDisplayMask) | sequence[i];
      delay(20);
    }
  }
  PORTB &= ~kDisplayMask;
}

void goToSleep() {
  set_sleep_mode(SLEEP_MODE_PWR_DOWN);
  sleep_enable();
  // Disable BOD during sleep to minimize power draw (~25 uA savings).
  // Must be called within 3 cycles of sleep_enable() per datasheet.
  sleep_bod_disable();
  // Atomic-style sleep: enable interrupts, then sleep, then disable.
  // Using sleep_mode() (which itself does sei+sleep_cpu+cli) races with
  // a pending PCINT and can return immediately. Explicit form is safer.
  sei();
  sleep_cpu();
  sleep_disable();
}

void setup() {
  DDRB |= kDisplayMask;
  DDRB &= ~kButtonMask;
  PORTB |= kButtonMask; // Enable internal pull-up for button

  GIMSK |= (1 << PCIE); // Pin Change Interrupt Enable
  PCMSK |= kButtonMask; // Enable interrupt for the button pin
  sei(); // Enable global interrupts

  mixEntropy(TCNT0);
  PORTB &= ~kDisplayMask; // Ensure all display groups are off at start
  runStartupTest();
}

// Runs the spin animation and result display. A fresh button press at any
// point (mid-spin or while the result is shown) restarts the roll right away.
void performRoll() {
  const uint16_t kRollStepMs = 30; // Constant spin speed, no slow-down.
  bool restart = true;
  while (restart) {
    restart = false;
    buttonInterruptPending = false;
    uint8_t rollCount = kDemoSpinCount * 2; // Roll spins twice as long as the demo.
    for (uint8_t i = 0; i <= rollCount; ++i) {
      showFace(randomFace());
      if (waitOrPressed(kRollStepMs)) {
        restart = true;
        break;
      }
    }
    // Last iteration already showed the result; no need to roll once more.
    if (!restart && waitOrPressed(1200)) { // Keep the result visible briefly
      restart = true;
    }
  }
  PORTB &= ~kDisplayMask; // Turn off all display groups
}

void loop() {
  if (buttonInterruptPending) {
    noInterrupts();
    buttonInterruptPending = false;
    uint8_t entropy = randomEntropy;
    interrupts();

    delay(25);
    if (!(PINB & kButtonMask)) {
      mixEntropy((entropy << 1) ^ PINB);
      performRoll();
    }
  }

  if (!buttonInterruptPending) {
    goToSleep(); // Go to sleep mode
  }
}

// Accumulate entropy across multiple edges instead of overwriting on
// each interrupt. A single TCNT0 sample is weak; XORing PINB and
// counting edges gives more bits per button press.
ISR(PCINT0_vect) {
  if (!(PINB & kButtonMask)) {
    randomEntropy ^= TCNT0;
    randomEntropy ^= PINB;
    edgeCounter++;
    buttonInterruptPending = true;
  }
}

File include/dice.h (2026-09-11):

// dice.h — Pure-logic header for the dice face mapping.
//
// This file is intentionally free of Arduino-specific includes so it can
// be compiled both by the ATtiny13A firmware and by the host-native test
// runner (PlatformIO `pio test -e native`).
//
// The hardware layout (PB0..PB3 as display segments, PB4 as the button)
// is fixed in stone at the schematic level — see docs/BOM.md and the
// main README. Changing these values here without changing the firmware
// pin mapping AND the KiCad schematic will produce a board that lights
// up the wrong segments.

#ifndef ARCDICE_DICE_H_
#define ARCDICE_DICE_H_

#include <stdint.h>

// Bit positions on ATtiny13A PORTB. Keep in sync with src/main.cpp.
#ifndef DICE_SEGMENT_CENTER
#define DICE_SEGMENT_CENTER     0   // PB0 — center pip (CC)
#endif
#ifndef DICE_SEGMENT_DIAGONAL_A
#define DICE_SEGMENT_DIAGONAL_A 1   // PB1 — TL + BR diagonal
#endif
#ifndef DICE_SEGMENT_DIAGONAL_B
#define DICE_SEGMENT_DIAGONAL_B 2   // PB2 — TR + BL diagonal
#endif
#ifndef DICE_SEGMENT_MIDDLE_ROW
#define DICE_SEGMENT_MIDDLE_ROW 3   // PB3 — ML + MR middle row
#endif

#define DICE_BUTTON_PIN         4   // PB4 — roll button input

#define DICE_BIT(bit)           ((uint8_t)(1u << (bit)))

namespace arcdice {

constexpr uint8_t kCenterMask     = DICE_BIT(DICE_SEGMENT_CENTER);
constexpr uint8_t kDiagonalAMask  = DICE_BIT(DICE_SEGMENT_DIAGONAL_A);
constexpr uint8_t kDiagonalBMask  = DICE_BIT(DICE_SEGMENT_DIAGONAL_B);
constexpr uint8_t kMiddleRowMask  = DICE_BIT(DICE_SEGMENT_MIDDLE_ROW);

constexpr uint8_t kButtonMask     = DICE_BIT(DICE_BUTTON_PIN);

constexpr uint8_t kDisplayMask =
    kCenterMask | kDiagonalAMask | kDiagonalBMask | kMiddleRowMask;

// Face indices are 0..6 inclusive. Face 0 is the "all off" sentinel
// (never displayed by the firmware — roll() returns 1..6) but is included
// here so the array length matches the README's 1..6 documentation.
//
// The mapping matches the README "Dice Face Layout" table:
//
//   face 1 = center
//   face 2 = diagonal A
//   face 3 = center + diagonal A           (vertical middle column)
//   face 4 = diagonal A + diagonal B       (full X, four corners)
//   face 5 = center + diagonals A + B      (full X + center)
//   face 6 = diagonals A + B + middle row  (four corners + middle two)
constexpr uint8_t kDiceFaceMasks[7] = {
    0,                                              // face 0 — unused
    kCenterMask,                                    // face 1
    kDiagonalAMask,                                  // face 2
    kCenterMask | kDiagonalAMask,                    // face 3
    kDiagonalAMask | kDiagonalBMask,                 // face 4
    kCenterMask | kDiagonalAMask | kDiagonalBMask,   // face 5
    kDiagonalAMask | kDiagonalBMask | kMiddleRowMask, // face 6
};

// Returns the PORTB mask for the requested face. Faces 1..6 are valid;
// face 0 returns 0 (all segments off). Out-of-range faces return 0xFF
// so a programming error is visible immediately rather than silently
// rolling "all off".
constexpr uint8_t faceMask(uint8_t face) {
    return (face < 7) ? kDiceFaceMasks[face] : 0xFF;
}

}  // namespace arcdice

#endif  // ARCDICE_DICE_H_

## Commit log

2026-07-12 Add firmware refinements and initial KiCad hardware design
    [digital-dice.kicad_pcb, digital-dice.kicad_sch]
2026-07-14 Update ArcDice project files
    [ArcDice.kicad_pcb, ArcDice.kicad_sch, digital-dice.kicad_pcb]
2026-07-14 Update hardware design
    [ArcDice.kicad_pcb]
2026-07-15 logo added
    [ArcDice.kicad_pcb]
2026-07-18 Fix BOD disable, edge entropy accumulation, and startup flash
    - Guard sleep_bod_disable() with #ifdef for toolchain portability
    - Replace PINB read in mixEntropy() with re-read randomEntropy to
    avoid read-write race with PCINT0_vect on ATtiny13A
    - Remove unused volatile edgeCounter
    - Clarify comments: DIAGONAL masks drive corner pairs, not diagonal
    LED chains; document PB4/RSTDISBL trade-off
    - Translate code comments to Hungarian (API names left in English)
    [main.cpp]
2026-07-18 Document dice faces, add RSTDISBL warning, ship Gerber V2
    - README.md: add a dice-face layout table (1-6) and a prominent
    warning about PB4 being the ATtiny13A RESET pin, which forces
    RSTDISBL to be programmed and disables ISP reprogramming.
    - KiCad project: point Gerber plot output at hardware/Gerber/V2/ and
    switch plated drill shape to circular (drillshape 0).
    - Add the V2 Gerber export set (copper, mask, paste, silkscreen,
    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
    [ArcDice-B_Cu.gbr, ArcDice-B_Mask.gbr, ArcDice-B_Paste.gbr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]
2026-07-19 docs: add CHANGELOG.md and docs/BOM.md, link from README
    - CHANGELOG.md in Keep-a-Changelog format, reconstructed from the
    full commit history (0.1.0 through 0.9.0), plus an Unreleased
    section listing the remaining release-readiness work.
    - docs/BOM.md with full bill of materials: ATtiny13A-P, 7x 5 mm
    THT LEDs, 7x 220 ohm resistors, 1x tactile push button, 2x SPDT
    switches, 1x TP4056 charger module, 1x 1S Li-ion cell, 2x
    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
2026-07-19 test: extract dice face-mask logic into include/dice.h, add unit tests
    The face-mapping constants (kCenterMask, kDisplayMask, diceFaceMasks[7])
    were previously inlined in src/main.cpp, which made them impossible to
    test without an AVR toolchain. They are now declared in
    include/dice.h as constexpr values inside the arcdice namespace, so
    they can be compiled both by the ATtiny13A firmware and by the host
    test runner.
    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
2026-07-19 release: prepare v1.0.0, add Build & Test CI badge
    - CHANGELOG.md: add [1.0.0] section with highlights and downstream
    user notes. Update [Unreleased] section to reflect what has shipped
    and what was deferred (assembly guide). Update footer compare links
    to anchor on v1.0.0.
    - README.md: add 'Build & Test' GitHub Actions status badge linking
    to the workflow runs page.
2026-07-19 docs: add CONTRIBUTING, CODE_OF_CONDUCT, issue & PR templates, Gerber V2 README
    - CODE_OF_CONDUCT.md: Contributor Covenant v2.1 (standard template,
    adapted for project size — contact via GitHub issue tracker).
    - CONTRIBUTING.md: workflow, branch naming (feat/fix/docs/hw/<slug>),
    Conventional Commits style, coding conventions for C++ and KiCad,
    test plan, release flow, label taxonomy. References the CI workflow
    by name so contributors know what's expected.
    - .github/ISSUE_TEMPLATE/config.yml: disables blank issues, routes
    doc questions to README/BOM/CHANGELOG, security issues to GitHub
    Security Advisories, discussion-style questions to Discussions.
    - .github/ISSUE_TEMPLATE/bug_r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
2026-09-11 feat: constant-speed roll animation, restart-on-press, running-light demo
    - performRoll() now spins at a constant rate (no deceleration curve) and
    restarts immediately if the button is pressed again mid-roll or while
    the result is displayed
    - Result face stays lit longer after a roll (1.2s)
    - Startup demo replaced with a running-light chase through the 4 LED
    groups, starting top-right, 3 laps
    - Removed incorrect PB4/RESET-pin/RSTDISBL claims from src/main.cpp,
    include/dice.h, README.md, and docs/BOM.md -- PB4 is a normal GPIO on
    the ATtiny13A (RESET is the separate PB5 pin)
    [dice.h, main.cpp]
2026-09-11 hardware: update KiCad schematic, PCB, and project files
    [ArcDice.kicad_pcb, ArcDice.kicad_sch]
2026-09-11 hardware: minor PCB update
    [ArcDice.kicad_pcb]
2026-09-11 hardware: regenerate Gerber V2 export
    [ArcDice-B_Cu.gbr, ArcDice-B_Mask.gbr, ArcDice-B_Paste.gbr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]
2026-09-12 docs: add real assembled/PCB photos to README gallery
2026-09-12 hardware: minor PCB/project update
    [ArcDice.kicad_pcb]
